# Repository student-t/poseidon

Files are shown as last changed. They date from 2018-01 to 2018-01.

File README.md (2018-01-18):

# Poseidon project - open source bioinstrumentation

Poseidon is an open source bioinstrumentation project. The goal is to develop instruments that are readily adoptable by biology labs.

## Open source syringe pumps and Raspberry Pi microscope
mvimg_20180111_222424

## All the parts for 3 pumps and a microscope cost under $400
mvimg_20180111_211022

## Assembly instructions for the Poseidon syringe pumps

Detailed written instructions are on the way, in the meantime you can [click here for a walkthrough video](https://photos.app.goo.gl/xIplnxrbvsixwfU03)

## Instructions for the pumps Arduino hardware

We use the [Arduino CNC shield](http://wiki.keyestudio.com/index.php/Ks0095_Arduino_CNC_Kit_/_CNC_Shield_V3.0_%2Bkeyestudio_Uno_R3%2B4pcs_a4988_Driver_/_GRBL_Compatible)
to allow for up to three pumps can be controlled from a computer or from the Rapsberry Pi microscope.

The software is configured to run the stepper motors with 200 steps per revolution at 1/4 microstepping, which translates to 800 steps per rotation. To configure this, it is necessary to add a jumper between the MODE1 pins of the Arduino CNC shield, as shown in the picture below. More information about microstepping can be found in the product page for the [DRV8825 Stepper Motor Driver](https://www.pololu.com/product/2133), which is used by the CNC shield. 

microsteppingpng

Here is how the board looks with the stepper motors connected:

full_board

## Assembly of the Raspberry Pi microscope 
 *Coming soon*
 
 ## Instructions for the pump Python controller
Before stating the python controller, make sure the Arduino is connected via USB to the computer or Rapsberry Pi microscope, that the CNC shield is powered, and that the 3 motors are plugged in. Test to see that they are moving in the correct direciton when expelling, if not simply invert the stepper motor connector orientation.

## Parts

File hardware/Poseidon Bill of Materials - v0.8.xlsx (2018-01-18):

Poseidon Pumps
Total for 3 pumps | $174.87 |  |  |  | Per pump total | 37.90810303
Part Number | Item Description | Package Cost | Packages for 3 pumps | Items per pump | Cost for 3 pumps | Cost per pump | Cost for single pump | Retailer | Items per pack | Price per item | Link
1 | Nema 17 Stepper Motor (Bipolar, 40mm, 45Ncm) | 33.99 | 1 | 1 | 33.99 | 11.33 | 33.99 | Amazon | 3 | 11.33 | https://www.amazon.com/Stepper-Holding-Printer-Beauty-Star/dp/B075S98D46
2 | 5mm to 5mm Motor Shaft Coupling | 22 | 1 | 1 | 22 | 2.2 | 22 | Amazon | 10 | 2.2 | https://www.amazon.com/Aluminum-Flexible-Coupling-Printing-Pack/dp/B01EFFBM4I?s=industrial
3 | 6mm Steel Rod (length 200mm, pack of 2) | 7.12 | 3 | 2 | 21.36 | 7.12 | 7.12 | Amazon | 2 | 3.56 | https://www.amazon.com/Steel-Round-Turning-Lathe-200mm/dp/B00LUSVKVY
4 | 6mm Linear Bearing (pack of 12) | 12.49 | 1 | 2 | 12.49 | 2.081666667 | 12.49 | Amazon | 12 | 1.040833333 | https://www.amazon.com/uxcell-6mmx12mmx19mm-Linear-Bushing-Bearing/dp/B01MTLSZFQ?s=industrial
5 | M5x0.8 Threaded Rod (length 170mm) | 9.14 | 1 | 1 | 9.14 | 1.828 | 9.14 | Amazon | 5 | 1.828 | https://www.amazon.com/uxcell-170mm-Stainless-Threaded-Fasteners/dp/B01M4L8JDC?s=industrial
6 | M5x0.8 nut | 7.2 | 1 | 1 | 7.2 | 0.144 | 7.2 | Amazon | 50 | 0.144 | https://www.amazon.com/uxcell-Metric-M5x0-8mm-Stainless-Finished/dp/B012T3C8YQ?s=industrial
7 | M3x0.5 socket head screws to mount motor (length 20mm) | 9.91 | 1 | 4 | 9.91 | 0.3964 | 9.91 | Amazon | 100 | 0.0991 | https://www.amazon.com/Stainless-Socket-Internal-Threaded-Threads/dp/B000FN21AO?s=industrial
8 | M3x0.5 socket head screws (hold rod in place, length 10mm) | 7.8 | 1 | 2 | 7.8 | 0.2836363636 | 7.8 | Amazon | 55 | 0.1418181818 | https://www.amazon.com/uxcell-M3x10mm-Thread-Stainless-Socket/dp/B01MFA9YEP?s=industrial
9 | M3 nut (hold rod in place) | 5.2 | 1 | 2 | 5.2 | 0.104 | 5.2 | Amazon | 100 | 0.052 | https://www.amazon.com/100Pcs-Female-Thread-Fastener-Silver/dp/B00GYS1SXU?s=industrial
10 | M5 knob (hold syringe in place) | 11.9 | 1 | 1 | 11.9 | 1.19 | 11.9 | Amazon | 10 | 1.19 | https://www.amazon.com/Kipp-06220-405X50-Thermoplastic-External-Diameter/dp/B013I72QTY?s=industrial
11 | 12V power unit (end stripped to fit CNC shield power input) | 15 | 1 | 1 | 15 | 5 | 5 | Amazon | 1 | 15 | https://www.amazon.com/Kastar-AC-Adapter-Power-LCD/dp/B003TUMDWG?s=electronics
12 | Arduino + CNC Shield Pack | 18.88 | 1 | 0.33 | 18.88 | 6.2304 | 18.88 | Amazon | 1 | 18.88 | https://www.amazon.com/Longruner-Expansion-Stepper-Heatsink-Arduino/dp/B06XJKVLG3
Poseidon Microscope
Total microscope | $211.69
Part Number | Item Description | Package Cost | Packages needed | Items needed | Cost | Items per pack | Retailer | Link
1 | Raspberry Pi Motherboard | 35.75 | 1 | 1 | 35.75 | 1 | Amazon | https://www.amazon.com/Raspberry-Pi-RASPBERRYPI3-MODB-1GB-Model-Motherboard/dp/B01CD5VC92?s=pc
2 | Raspberry Pi 7" touchscreen display | 69.99 | 1 | 1 | 69.99 | 1 | Amazon | https://www.amazon.com/Raspberry-Pi-7-Touchscreen-Display/dp/B0153R2A9I
3 | Raspberry Pi Power Suppy (5v 1.5A DC) | 9.99 | 1 | 1 | 9.99 | 1 | Amazon | https://www.amazon.com/CanaKit-Raspberry-Supply-Adapter-Charger/dp/B00MARDJZ4?s=electronics
4 | 16gb MicroSD card (comes with adapter) | 6.95 | 1 | 1 | 6.95 | 1 | Amazon | https://www.amazon.com/SanDisk-16GB-Micro-SDHC-Memory/dp/B004G605OA?s=electronics
5 | Raspberry Pi 8MP Camera 1080p video | 33.99 | 1 | 1 | 33.99 | 1 | Amazon | https://www.amazon.com/Raspberry-Pi-Camera-Module-Megapixel/dp/B01ER2SKFS?s=electronics
6 | Keyboard + Mouse Bundle (wired) | 13.09 | 1 | 1 | 13.09 | 1 | Amazon | https://www.amazon.com/AmazonBasics-Wired-Keyboard-Mouse-Bundle/dp/B00B7GV802?s=electronics
7 | M3x0.5 Socket Head Screws (length 10mm) | 7.8 | 1 | 4 | 7.8 | 55 | Amazon | https://www.amazon.com/uxcell-M3x10mm-Thread-Stainless-Socket/dp/B01MFA9YEP?s=industrial
8 | M5x0.8 Socket Head Screw (length 14mm) | 8.61 | 1 | 8 | 8.61 | 15 | Amazon | https://www.amazon.com/uxcell-M5x14mm-Stainless-Metric-Thread/dp/B01LJROXK0
9 | Diode Lens (magnifying lens) 7mm | 9.47 | 1 | 1 | 9.47 | 5 | Amazon | https://www.amazon.com/Collimating-focusing-Diameter-Laser-Diodes/dp/B00PPSJJ40
10 | M5x0.8 nuts | 7.2 | 1 | 8 | 7.2 | 50 | Amazon | https://www.amazon.com/uxcell-Metric-M5x0-8mm-Stainless-Finished/dp/B012T3C8YQ?s=industrial
11 | M2 screw (length 20mm) | 5 | 1 | 4 | 5 | 25 | Amazon | https://www.amazon.com/uxcell-Thread-Socket-Screws-Bolts/dp/B01FL88JJO?srs=3049510011
12 | USB LED Light | 3.85 | 1 | 1 | 3.85 | 1 | Amazon | https://www.amazon.com/Daffodil-ULT05-USB-LED-Light/dp/B00BWTYMPM
13 | M2 Standoffs and nuts (length 10mm) | 9.99 | 1 | 4 | 9.99 | 25 | Amazon | https://www.amazon.com/250Pcs-Standoff-Pillars-Assortment-Storage/dp/B071VJCDG8

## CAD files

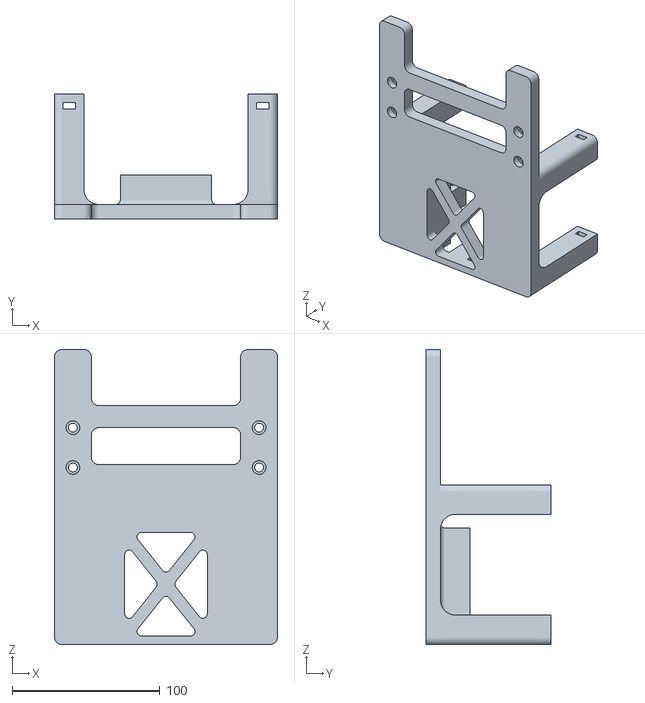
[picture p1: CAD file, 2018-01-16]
hardware/piscope_base_v0.6.stl
151.2 x 85.0 x 200.0

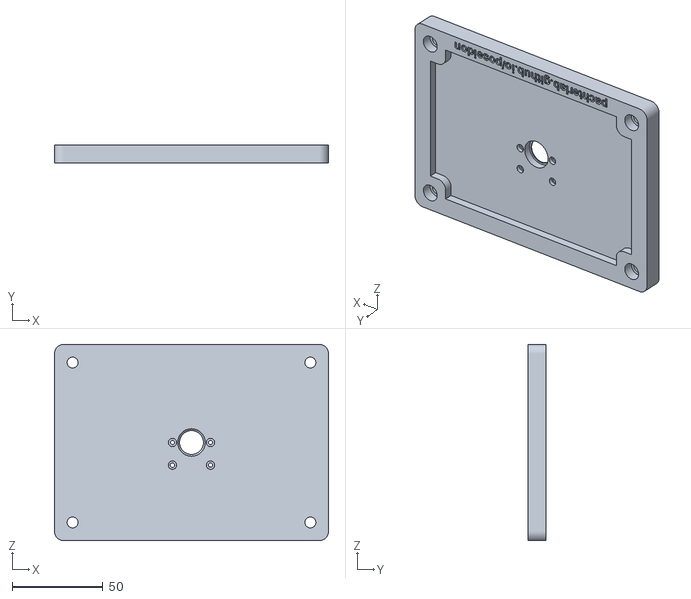
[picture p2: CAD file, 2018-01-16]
hardware/piscope_stage_v0.6.stl
151.2 x 10.0 x 108.3

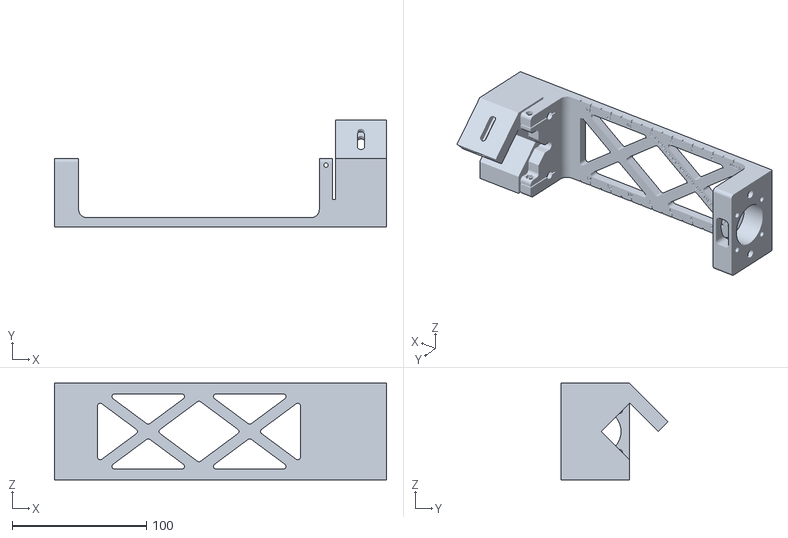
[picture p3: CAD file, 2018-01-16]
hardware/pump_base_v0.8.stl
247.0 x 79.6 x 72.0

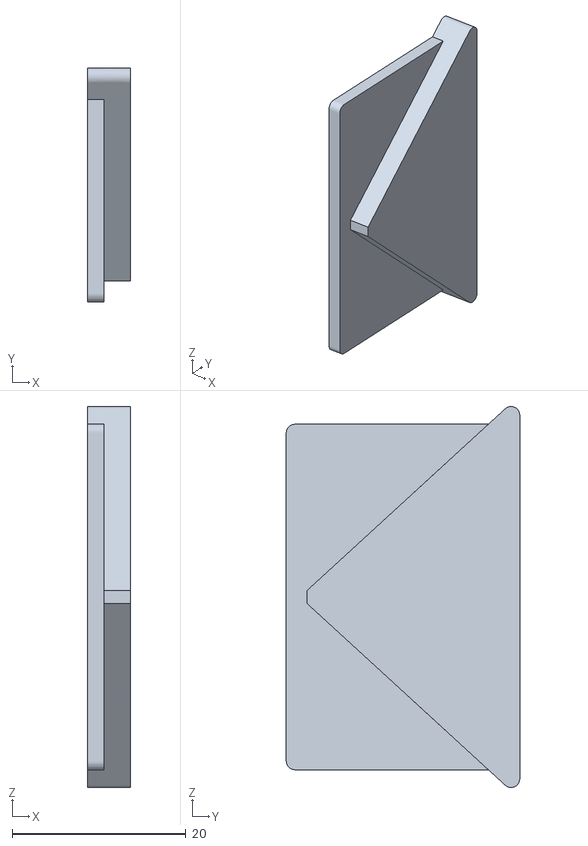
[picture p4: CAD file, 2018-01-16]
hardware/pump_slide_v0.8.stl
5.00 x 26.9 x 43.9

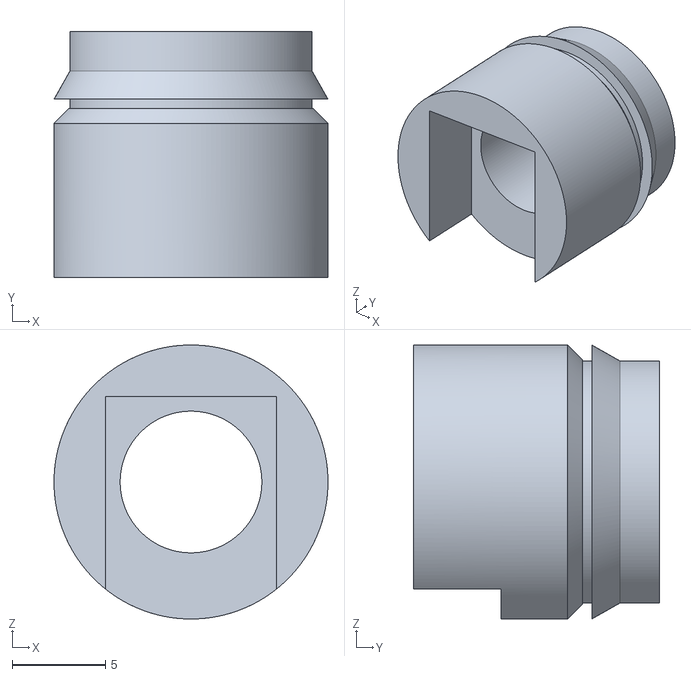
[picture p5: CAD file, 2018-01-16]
hardware/piscope_lens_mount_v0.6.stl
14.7 x 13.2 x 14.7

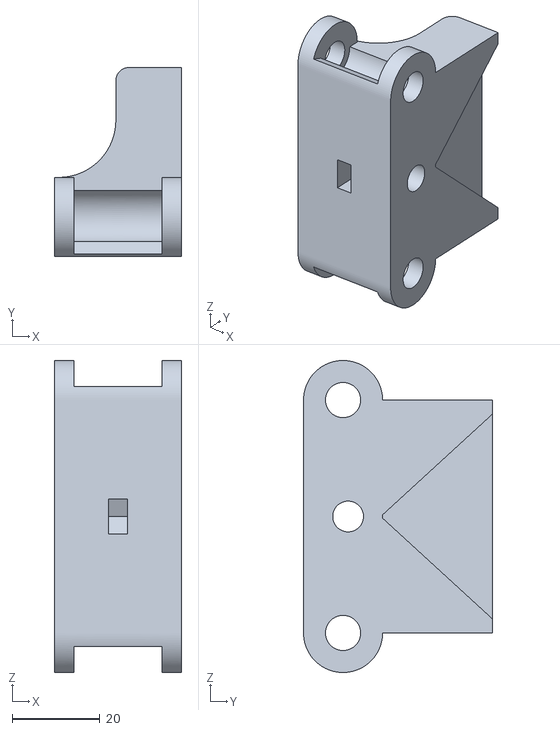
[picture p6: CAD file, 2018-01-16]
hardware/pump_carriage_v0.8.stl
29.0 x 43.0 x 71.0

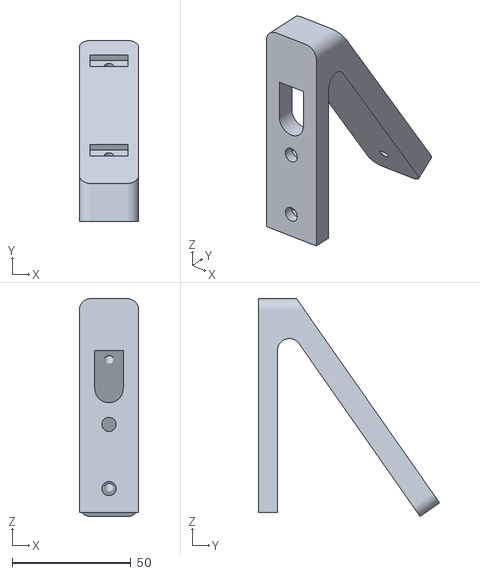
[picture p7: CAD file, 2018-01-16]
hardware/piscope_screen_mount_v0.6.stl
25.0 x 76.2 x 91.7

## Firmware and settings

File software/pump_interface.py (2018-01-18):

#!/usr/bin/python3

# pump_interface.py
# A PyQt5-based interface for running the open-source Poseidon microfludic 
# pumps.

# Python standard library includes
import sys
import time
import os
import platform

# Non-standard Python library includes
from PyQt5.QtCore import Qt, pyqtSlot, QPoint, QTimer
from PyQt5.QtWidgets import (QApplication, QLabel, QWidget, QGridLayout,
                             QSpinBox, QComboBox, QPushButton, QTabWidget,
                             QDoubleSpinBox, QScrollArea, QFrame)
from PyQt5.QtGui import QFont

# Local intra-package includes
from pymata_aio.pymata3 import PyMata3

# Define custom exception for handling system-dependent imports
class SytemNotDeterminedException(Exception):
    pass

# Platform-dependent include and platform determination
platform_name = ""
if platform.system()=="Windows":
    platform_name = "windows"
elif platform.system()=="Darwin":
    platform_name = "mac"
else:
    platform_information = os.uname()
    if platform_information[1]=="raspberrypi" and \
            platform_information[4][:3]=="arm":
        import picamera
        platform_name = "raspi"
    elif platform_information[0]=="Linux" and \
            platform_information[4][:3]=="x86":
        plaform_name = "linux"
    else:
        raise SystemNotDeterminedException( \
                "What strange system are you running on?")


class QHLine(QFrame):
    def __init__(self):
        super().__init__()
        self.setFrameShape(QFrame.HLine)
        self.setFrameShadow(QFrame.Sunken)


class Pump_interface(QWidget):

    def __init__(self):
        super().__init__()

        if platform_name=="raspi":
            self.camera = picamera.PiCamera()
        
        self.initHardwareConstants()
        self.initBoard()
        self.initUIrefreshLoop()
        self.initGlobalVariables()
        self.initUI()

    def initHardwareConstants(self):
        self.steps_per_rev = 800
        self.mm_per_rev = 0.8
        self.syringe_mm_per_ml_dict = {}
        self.syringe_mm_per_ml_dict["3mL"] = 17.0
        self.syringe_mm_per_ml_dict["10mL"] = 6.0
        self.syringe_mm_per_ml_dict["60mL"] = 1.5

    def initBoard(self):
        self.board = PyMata3( log_output=True, arduino_wait=5)
        # initializing X stepper with device number 0
        self.board.get_pin_state(2)
        self.board.accelstepper_config( 0, 1, 1, 0, [2,5])
        self.board.get_pin_state(2)
        # initializing Y stepper with device number 1
        self.board.accelstepper_config( 1, 1, 1, 0, [3,6])
        # initializing Z stepper with device number 2
        self.board.accelstepper_config( 2, 1, 1, 0, [4,7])

    def initUIrefreshLoop(self):
        self.ui_refresh_timer = QTimer()
        self.ui_refresh_timer.timeout.connect(self.ui_refresh)
        self.ui_refresh_timer.start(700)

    def initGlobalVariables(self):
        # Motor state variables
        # ["running", "paused", "stopped"]
        self.pump_one_state = "stopped"
        self.pump_two_state = "stopped"
        self.pump_three_state = "stopped"
        self.pump_one_total_steps = 0.00
        self.pump_two_total_steps = 0.00
        self.pump_three_total_steps = 0.00
        self.pump_one_final_speed = 0.00
        self.pump_two_final_speed = 0.00
        self.pump_three_final_speed = 0.00
        self.pump_one_total_distance = 0.00
        self.pump_two_total_distance = 0.00
        self.pump_three_total_distance = 0.00
        self.pump_one_total_distance_units = 0.00
        self.pump_two_total_distance_units = 0.00
        self.pump_three_total_distance_units = 0.00
        self.pump_one_total_time = 0.00
        self.pump_two_total_time = 0.00
        self.pump_three_total_time = 0.00
        self.pump_one_start_time = 0.00
        self.pump_two_start_time = 0.00
        self.pump_three_start_time = 0.00
        self.pump_one_time_running_fraction = 0.00
        self.pump_two_time_running_fraction = 0.00
        self.pump_three_time_running_fraction = 0.00
        self.pump_one_last_timestamp = 0.00
        self.pump_two_last_timestamp = 0.00
        self.pump_three_last_timestamp = 0.00
        self.camera_showing = 0

    def initUI(self):
        self.create_widgets()
        self.style_widgets()
        self.attach_widget_callbacks()
        if platform_name=="raspi":
            self.place_widgets_raspi()
        else:
            self.place_widgets()

    def create_widgets(self):
        ## Pumps Tab -- titles
        if platform_name=="raspi":
            self.pump_one_speed_label = QLabel("Speed", self)
            self.pump_one_speed_label.setAlignment(Qt.AlignHCenter)
            self.pump_one_distance_label = QLabel("Distance", self)
            self.pump_one_distance_label.setAlignment(Qt.AlignHCenter)
            self.pump_one_direction_label = QLabel("Direction", self)
            self.pump_one_direction_label.setAlignment(Qt.AlignHCenter)
            self.pump_one_syringe_label = QLabel("Syringe", self)
            self.pump_one_syringe_label.setAlignment(Qt.AlignHCenter)
            self.pump_one_speed_readout_label = QLabel("Current Speed", self)
            self.pump_one_speed_readout_label.setAlignment(Qt.AlignHCenter)
            self.pump_one_distance_traveled_label = QLabel(
                    "Distance Traveled", self)
            self.pump_one_distance_traveled_label.setAlignment(Qt.AlignHCenter)
            self.pump_one_distance_set_label = QLabel("Distance Set", self)
            self.pump_one_distance_set_label.setAlignment(Qt.AlignHCenter)
            self.pump_one_distance_remaining_label = QLabel(
                    "Distance Remaining", self)
            self.pump_one_distance_remaining_label.setAlignment(Qt.AlignHCenter)

            self.pump_two_speed_label = QLabel("Speed", self)
            self.pump_two_speed_label.setAlignment(Qt.AlignHCenter)
            self.pump_two_distance_label = QLabel("Distance", self)
            self.pump_two_distance_label.setAlignment(Qt.AlignHCenter)
            self.pump_two_direction_label = QLabel("Direction", self)
            self.pump_two_direction_label.setAlignment(Qt.AlignHCenter)
            self.pump_two_syringe_label = QLabel("Syringe", self)
            self.pump_two_syringe_label.setAlignment(Qt.AlignHCenter)
            self.pump_two_speed_readout_label = QLabel("Current Speed", self)
            self.pump_two_speed_readout_label.setAlignment(Qt.AlignHCenter)
            self.pump_two_distance_traveled_label = QLabel(
                    "Distance Traveled", self)
            self.pump_two_distance_traveled_label.setAlignment(Qt.AlignHCenter)
            self.pump_two_distance_set_label = QLabel("Distance Set", self)
            self.pump_two_distance_set_label.setAlignment(Qt.AlignHCenter)
            self.pump_two_distance_remaining_label = QLabel(
                    "Distance Remaining", self)
            self.pump_two_distance_remaining_label.setAlignment(Qt.AlignHCenter)

            self.pump_three_speed_label = QLabel("Speed", self)
            self.pump_three_speed_label.setAlignment(Qt.AlignHCenter)
            self.pump_three_distance_label = QLabel("Distance", self)
            self.pump_three_distance_label.setAlignment(Qt.AlignHCenter)
            self.pump_three_direction_label = QLabel("Direction", self)
            self.pump_three_direction_label.setAlignment(Qt.AlignHCenter)
            self.pump_three_syringe_label = QLabel("Syringe", self)
            self.pump_three_syringe_label.setAlignment(Qt.AlignHCenter)
            self.pump_three_speed_readout_label = QLabel("Current Speed", self)
            self.pump_three_speed_readout_label.setAlignment(Qt.AlignHCenter)
            self.pump_three_distance_traveled_label = QLabel(
                    "Distance Traveled", self)
            self.pump_three_distance_traveled_label.setAlignment(Qt.AlignHCenter)
            self.pump_three_distance_set_label = QLabel("Distance Set", self)
            self.pump_three_distance_set_label.setAlignment(Qt.AlignHCenter)
            self.pump_three_distance_remaining_label = QLabel(
                    "Distance Remaining", self)
            self.pump_three_distance_remaining_label.setAlignment(Qt.AlignHCenter)
        else:
            self.title_speed_label = QLabel("Speed", self)
            self.title_speed_label.setAlignment(Qt.AlignHCenter)
            self.title_distance_label = QLabel("Distance", self)
            self.title_distance_label.setAlignment(Qt.AlignHCenter)
            self.title_direction_label = QLabel("Direction", self)
            self.title_direction_label.setAlignment(Qt.AlignHCenter)
            self.title_syringe_label = QLabel("Syringe", self)
            self.title_syringe_label.setAlignment(Qt.AlignHCenter)
            self.title_speed_readout_label = QLabel("Current Speed", self)
            self.title_speed_readout_label.setAlignment(Qt.AlignHCenter)
            self.title_distance_traveled_label = QLabel(
                    "Distance Traveled", self)
            self.title_distance_traveled_label.setAlignment(Qt.AlignHCenter)
            self.title_distance_set_label = QLabel("Distance Set", self)
            self.title_distance_set_label.setAlignment(Qt.AlignHCenter)
            self.title_distance_remaining_label = QLabel(
                    "Distance Remaining", self)
            self.title_distance_remaining_label.setAlignment(Qt.AlignHCenter)

        ## Pumps Tab -- Pump-specific
        self.pump_one_label = QLabel("Pump 1", self)
        self.pump_two_label = QLabel("Pump 2", self)
        self.pump_three_label = QLabel("Pump 3", self)

        self.pump_one_speed = QDoubleSpinBox(self)
        self.pump_two_speed = QDoubleSpinBox(self)
        self.pump_three_speed = QDoubleSpinBox(self)
        
        self.pump_one_speed_units = QComboBox(self)
        self.pump_one_speed_units.addItem('mm/s')
        self.pump_one_speed_units.addItem('mL/hr')
        self.pump_two_speed_units = QComboBox(self)
        self.pump_two_speed_units.addItem('mm/s')
        self.pump_two_speed_units.addItem('mL/hr')
        self.pump_three_speed_units = QComboBox(self)
        self.pump_three_speed_units.addItem('mm/s')
        self.pump_three_speed_units.addItem('mL/hr')

        self.pump_one_distance = QDoubleSpinBox(self)
        self.pump_one_distance.setSpecialValueText(u'    \u221e')
        self.pump_two_distance = QDoubleSpinBox(self)
        self.pump_two_distance.setSpecialValueText(u'    \u221e')
        self.pump_three_distance = QDoubleSpinBox(self)
        self.pump_three_distance.setSpecialValueText(u'    \u221e')

        self.pump_one_distance_units = QComboBox(self)
        self.pump_one_distance_units.addItem('mm')
        self.pump_one_distance_units.addItem('mL')
        self.pump_two_distance_units = QComboBox(self)
        self.pump_two_distance_units.addItem('mm')
        self.pump_two_distance_units.addItem('mL')
        self.pump_three_distance_units = QComboBox(self)
        self.pump_three_distance_units.addItem('mm')
        self.pump_three_distance_units.addItem('mL')
        
        self.pump_one_direction = QComboBox(self)
        self.pump_one_direction.addItem('infuse')
        self.pump_one_direction.addItem('withdraw')
        self.pump_two_direction = QComboBox(self)
        self.pump_two_direction.addItem('infuse')
        self.pump_two_direction.addItem('withdraw')
        self.pump_three_direction = QComboBox(self)
        self.pump_three_direction.addItem('infuse')
        self.pump_three_direction.addItem('withdraw')
        
        self.pump_one_syringe = QComboBox(self)
        self.pump_one_syringe.addItem('3mL')
        self.pump_one_syringe.addItem('10mL')
        self.pump_one_syringe.addItem('60mL')
        self.pump_two_syringe = QComboBox(self)
        self.pump_two_syringe.addItem('3mL')
        self.pump_two_syringe.addItem('10mL')
        self.pump_two_syringe.addItem('60mL')
        self.pump_three_syringe = QComboBox(self)
        self.pump_three_syringe.addItem('3mL')
        self.pump_three_syringe.addItem('10mL')
        self.pump_three_syringe.addItem('60mL')

        self.pump_one_run = QPushButton('Run', self)
        self.pump_two_run = QPushButton('Run', self)
        self.pump_three_run = QPushButton('Run', self)

        self.pump_one_stop = QPushButton('Stop', self)
        self.pump_two_stop = QPushButton('Stop', self)
        self.pump_three_stop = QPushButton('Stop', self)

        self.pump_one_speed_readout = QLabel("0.00", self)
        self.pump_two_speed_readout = QLabel("0.00", self)
        self.pump_three_speed_readout = QLabel("0.00", self)        
        self.pump_one_speed_units_readout = QLabel("", self)
        self.pump_two_speed_units_readout = QLabel("", self)
        self.pump_three_speed_units_readout = QLabel("", self)
       
        self.pump_one_distance_traveled = QLabel("0.00", self)
        self.pump_two_distance_traveled = QLabel("0.00", self)
        self.pump_three_distance_traveled = QLabel("0.00", self)        
        self.pump_one_distance_traveled_units = QLabel("", self)
        self.pump_two_distance_traveled_units = QLabel("", self)
        self.pump_three_distance_traveled_units = QLabel("", self)
       
        self.pump_one_distance_set = QLabel("0.00", self)
        self.pump_two_distance_set = QLabel("0.00", self)
        self.pump_three_distance_set = QLabel("0.00", self)        
        self.pump_one_distance_set_units = QLabel("", self)
        self.pump_two_distance_set_units = QLabel("", self)
        self.pump_three_distance_set_units = QLabel("", self)
       
        self.pump_one_distance_remaining = QLabel("0.00", self)
        self.pump_two_distance_remaining = QLabel("0.00", self)
        self.pump_three_distance_remaining = QLabel("0.00", self)        
        self.pump_one_distance_remaining_units = QLabel("", self)
        self.pump_two_distance_remaining_units = QLabel("", self)
        self.pump_three_distance_remaining_units = QLabel("", self)

        self.run_all_pumps = QPushButton('Run All Pumps', self)
        self.stop_all_pumps = QPushButton('Stop All Pumps', self)
        
        ## Camera Tab
        if platform_name=="raspi":
            self.view_camera = QPushButton(' Click to View/Hide Camera', self)

        ## Settings Tab
        if platform_name=="raspi":
            self.window_close = QPushButton('Close Program', self)

    def style_widgets(self):
        # Set some button styles
        self.run_button_style_string = """
            .QPushButton {
                background-color: #33cc33;
            }
        """
        self.pause_button_style_string = """
            .QPushButton {
                background-color: #0000ff;
            }
        """
        self.stop_button_style_string = """
            .QPushButton {
                background-color: #ff0000;
            }
        """
        self.pump_one_run.setStyleSheet(self.run_button_style_string)
        self.pump_two_run.setStyleSheet(self.run_button_style_string)
        self.pump_three_run.setStyleSheet(self.run_button_style_string)
        self.pump_one_stop.setStyleSheet(self.stop_button_style_string)
        self.pump_two_stop.setStyleSheet(self.stop_button_style_string)
        self.pump_three_stop.setStyleSheet(self.stop_button_style_string)
        self.run_all_pumps.setStyleSheet(self.run_button_style_string)
        self.stop_all_pumps.setStyleSheet(self.stop_button_style_string)

        # Set label fonts
        header_font = QFont()
        header_font.setBold(True)
        self.pump_one_label.setFont(header_font)
        self.pump_two_label.setFont(header_font)
        self.pump_three_label.setFont(header_font)
        if platform_name=="raspi":
            self.pump_one_speed_label.setFont(header_font)
            self.pump_one_distance_label.setFont(header_font)
            self.pump_one_direction_label.setFont(header_font)
            self.pump_one_syringe_label.setFont(header_font)
            self.pump_two_speed_label.setFont(header_font)
            self.pump_two_distance_label.setFont(header_font)
            self.pump_two_direction_label.setFont(header_font)
            self.pump_two_syringe_label.setFont(header_font)
            self.pump_three_speed_label.setFont(header_font)
            self.pump_three_distance_label.setFont(header_font)
            self.pump_three_direction_label.setFont(header_font)
            self.pump_three_syringe_label.setFont(header_font)
        else:
            self.title_speed_label.setFont(header_font)
            self.title_distance_label.setFont(header_font)
            self.title_direction_label.setFont(header_font)
            self.title_syringe_label.setFont(header_font)
            self.title_speed_readout_label.setFont(header_font)
            self.title_distance_traveled_label.setFont(header_font)
            self.title_distance_set_label.setFont(header_font)
            self.title_distance_remaining_label.setFont(header_font)

        # Set some necessary names
        self.pump_one_run.setObjectName('pump_one_run')
        self.pump_two_run.setObjectName('pump_two_run')
        self.pump_three_run.setObjectName('pump_three_run')
        self.pump_one_stop.setObjectName('pump_one_stop')
        self.pump_two_stop.setObjectName('pump_two_stop')
        self.pump_three_stop.setObjectName('pump_three_stop')


    def attach_widget_callbacks(self):
        self.pump_one_run.clicked.connect( self.run_button_click )
        self.pump_two_run.clicked.connect( self.run_button_click )
        self.pump_three_run.clicked.connect( self.run_button_click )
        self.run_all_pumps.clicked.connect( self.run_all_pumps_button_click )

        self.pump_one_stop.clicked.connect( self.stop_button_click )
        self.pump_two_stop.clicked.connect( self.stop_button_click )
        self.pump_three_stop.clicked.connect( self.stop_button_click )
        self.stop_all_pumps.clicked.connect( self.stop_all_pumps_button_click )

        if platform_name=="raspi":
            self.view_camera.clicked.connect( self.camera_preview )
            self.window_close.clicked.connect( self.close_button_clicked )

    def place_widgets(self):

        ## Tabs
        self.tabs = QTabWidget(self)
        self.tab1 = QWidget(self)
        self.tabs.addTab(self.tab1, "Pumps")

        ## Tab 1 Layout
        self.tab1_grid = QGridLayout()
        self.tab1_grid.setSpacing(10)

        self.tab1_grid.addWidget(self.title_speed_label, 1, 1, 1, 2)
        self.tab1_grid.addWidget(self.title_distance_label, 1, 3, 1, 2)
        self.tab1_grid.addWidget(self.title_direction_label, 1, 5)
        self.tab1_grid.addWidget(self.title_syringe_label, 1, 6)
        self.tab1_grid.addWidget(self.title_speed_readout_label, 1, 9, 1, 2)
        self.tab1_grid.addWidget(self.title_distance_traveled_label, 
                1, 11, 1, 2)
        self.tab1_grid.addWidget(self.title_distance_set_label, 1, 13, 1, 2)
        self.tab1_grid.addWidget(self.title_distance_remaining_label, 
                1, 15, 1, 2)
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

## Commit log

2018-01-16 Added stl files
    [piscope_base_v0.6.stl, piscope_lens_mount_v0.6.stl, piscope_screen_mount_v0.6.stl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]
2018-01-16 moves STLs into hardware folder
    [piscope_base_v0.6.stl, piscope_lens_mount_v0.6.stl, piscope_screen_mount_v0.6.stl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]
2018-01-18 added platform detection and platform-dependence for the camera functionality
2018-01-18 added new layout for raspberry pi
2018-01-18 Add bill of materials
    [Poseidon Bill of Materials - v0.8.xlsx]
2018-01-18 completely reworked raspi UI, cleaned up other UIs, and even got the camera working!
    [pump_interface.py]
2018-01-18 fixed Windows issue with os.uname() not existing
    [pump_interface.py]
